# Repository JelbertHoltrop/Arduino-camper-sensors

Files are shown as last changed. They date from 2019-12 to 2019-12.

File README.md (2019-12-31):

# Arduino-camper-sensors
An arduino mega based board to monitor air quality, current usage, waste water tank level.
The board uses a BME680 sensor for temperature, pressure, humidity and VOC gas sensor.
For current it uses a INA280 current sensor
For the water level it uses tree elektrodes. Between two poles in the bottom of the tank a reference is taken to measure the condustiveness of the fluid, waste water changes conductivity. The other elektrode is a long bare wire (goldplated) and is used to measure the fluid level. 

Many of the Arduino MEGA 2560 pins are avaliable on screw terminals on the edge of the board. 7 digital lines have a ULN2003 driver output.
On the board is a 240x320 touch screen shield attached for the gui.
The schematic and PCB files are made in Eagle. The pcb is simple and single sided.

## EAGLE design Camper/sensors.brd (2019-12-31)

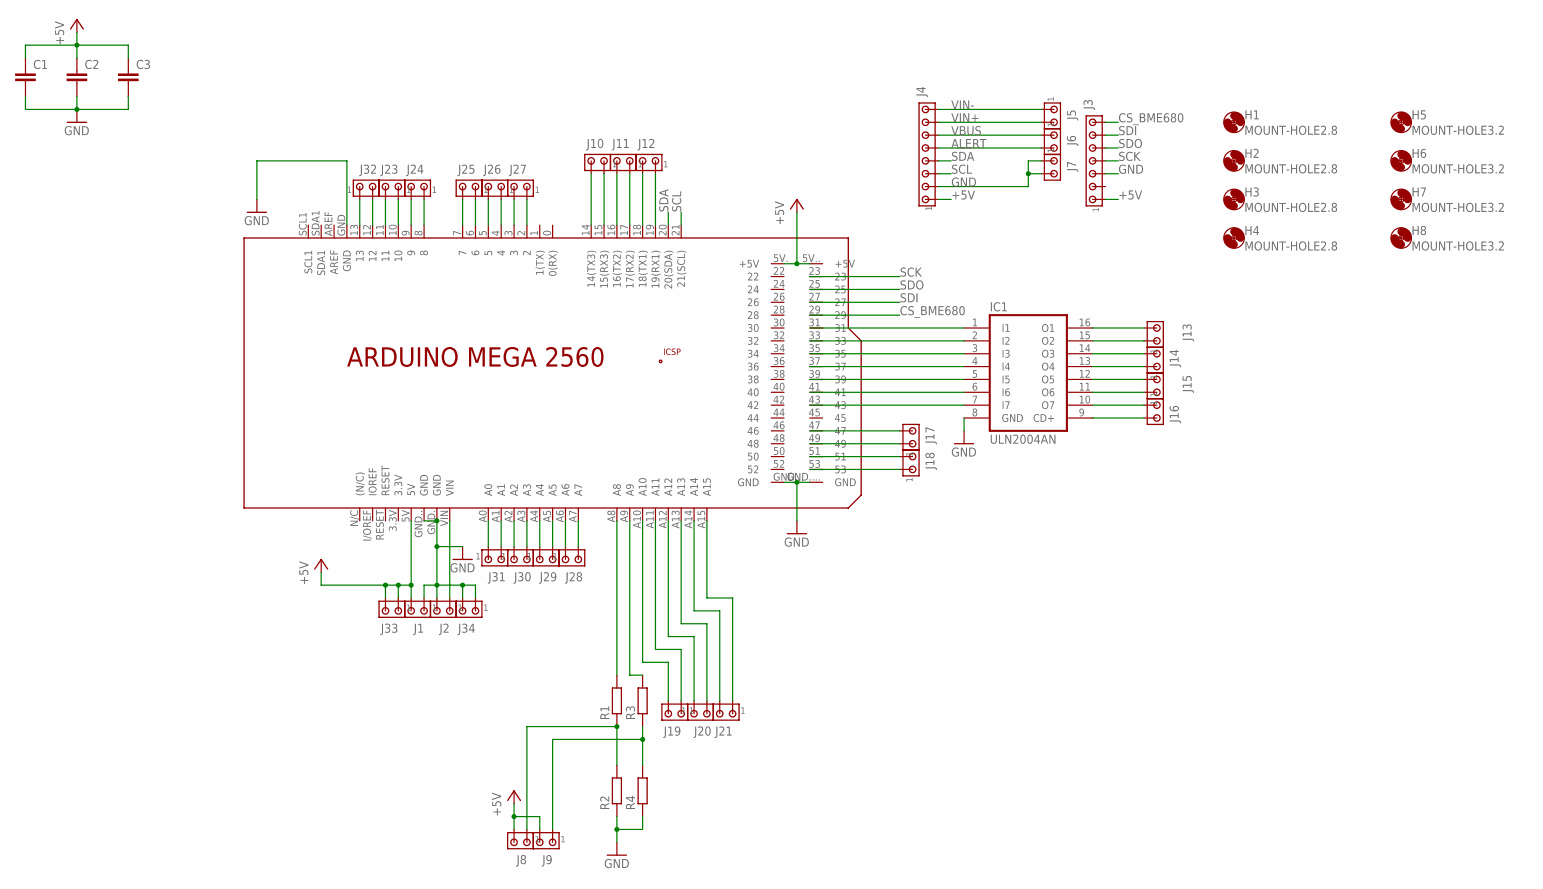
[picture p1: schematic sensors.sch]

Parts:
C1, C2, C3: C2,5-3; C2.5-3
H1, H2, H3, H4: MOUNT-HOLE2.8; 2,8
H5, H6, H7, H8: MOUNT-HOLE3.2; 3,2
IC1: ULN2004AN; DIL16
J1, J2, J5, J6, J7, J8, J9, J10, J11, J12, J13, J14, J15, J16, J17, J18, J19, J20, J21, J23, J24, J25, J26, J27, J28, J29, J30, J31, J32, J33, J34: SCREW-2
J3: MTA07-100; 10X07MTA
J4: MTA08-100; 10X08MTA
PCB1: ARDUINO_MEGA2560_NEW; ARDUINO_MEGA2560
R1, R2, R3, R4: R0207/10; 0207/10

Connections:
+5V: C1.1, C2.1, C3.1, J1.2, J3.1, J4.1, J8.2, J9.2, J33.1, J33.2, PCB1.5V, PCB1.5V. (+5V), PCB1.5V.. (+5V)
ALERT: J4.5, J6.2
CS_BME680: J3.7, PCB1.29
GND: C1.2, C2.2, C3.2, IC1.8 (GND), J1.1, J2.2, J3.3, J4.2, J7.1, J7.2, J34.1, J34.2, PCB1.GND, PCB1.GND. (GND), PCB1.GND.. (GND), PCB1.GND... (GND), PCB1.GND.... (GND), R2.1, R4.1
unnamed: J2.1, PCB1.VIN
unnamed: PCB1.A8, R1.2
unnamed: J8.1, R1.1, R2.2
unnamed: PCB1.A9, R3.2
unnamed: J9.1, R3.1, R4.2
unnamed: J19.2, PCB1.A10
unnamed: J19.1, PCB1.A11
unnamed: J20.1, PCB1.A12
unnamed: J20.2, PCB1.A13
unnamed: J21.2, PCB1.A14
unnamed: J21.1, PCB1.A15
unnamed: IC1.1 (I1), PCB1.31
unnamed: IC1.2 (I2), PCB1.33
unnamed: IC1.3 (I3), PCB1.35
unnamed: IC1.4 (I4), PCB1.37
unnamed: IC1.5 (I5), PCB1.39
unnamed: IC1.6 (I6), PCB1.41
unnamed: IC1.7 (I7), PCB1.43
unnamed: IC1.16 (O1), J13.2
unnamed: IC1.15 (O2), J13.1
unnamed: IC1.14 (O3), J14.2
unnamed: IC1.13 (O4), J14.1
unnamed: IC1.12 (O5), J15.2
unnamed: IC1.11 (O6), J15.1
unnamed: IC1.10 (O7), J16.1
unnamed: IC1.9 (CD+), J16.2
unnamed: J10.2, PCB1.14 (14(TX3))
unnamed: J10.1, PCB1.15 (15(RX3))
unnamed: J11.2, PCB1.16 (16(TX2))
unnamed: J11.1, PCB1.17 (17(RX2))
unnamed: J12.2, PCB1.18 (18(TX1))
unnamed: J12.1, PCB1.19 (19(RX1))
unnamed: J32.1, PCB1.13
unnamed: J32.2, PCB1.12
unnamed: J23.2, PCB1.11
unnamed: J23.1, PCB1.10
unnamed: J24.2, PCB1.9
unnamed: J24.1, PCB1.8
unnamed: J25.2, PCB1.7
unnamed: J25.1, PCB1.6
unnamed: J26.2, PCB1.5
unnamed: J26.1, PCB1.4
unnamed: J27.2, PCB1.3
unnamed: J27.1, PCB1.2
unnamed: J18.1, PCB1.53
unnamed: J18.2, PCB1.51
unnamed: J17.1, PCB1.49
unnamed: J17.2, PCB1.47
unnamed: J31.1, PCB1.A0
unnamed: J31.2, PCB1.A1
unnamed: J30.1, PCB1.A2
unnamed: J30.2, PCB1.A3
unnamed: J29.1, PCB1.A4
unnamed: J29.2, PCB1.A5
unnamed: J28.1, PCB1.A6
unnamed: J28.2, PCB1.A7
SCK: J3.4, PCB1.23
SCL: J4.3, PCB1.21 (21(SCL))
SDA: J4.4, PCB1.20 (20(SDA))
SDI: J3.6, PCB1.27
SDO: J3.5, PCB1.25
VBUS: J4.6, J6.1
VIN+: J4.7, J5.2
VIN-: J4.8, J5.1

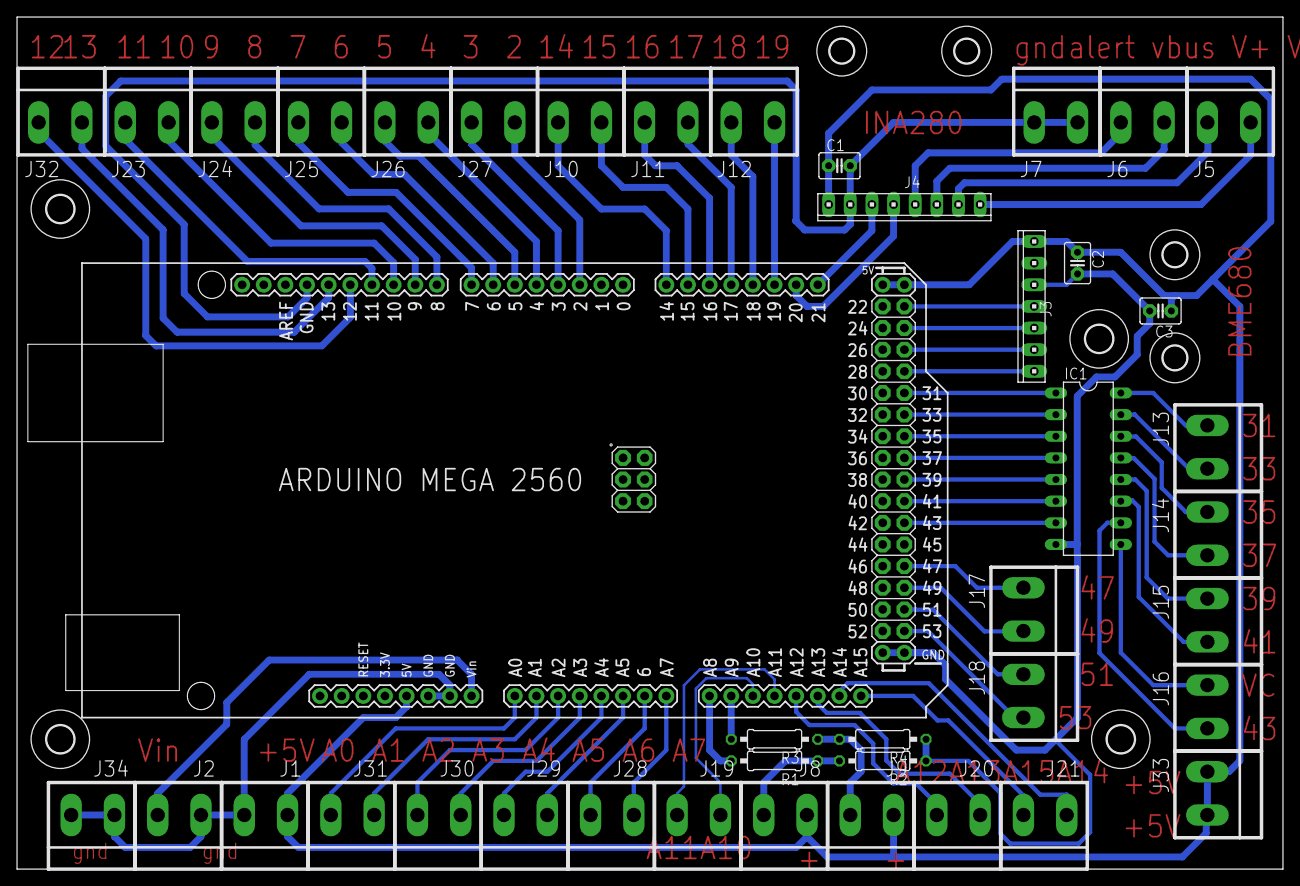
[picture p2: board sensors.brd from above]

Board: 2 copper layers, 148.6 x 100.0 mm, 50 parts (0 on the bottom side), 68 nets.

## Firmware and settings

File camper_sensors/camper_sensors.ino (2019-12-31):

/*
 * Arduino mega bordje gemaakt waar het display op past
 * Sensors:
 * BME680:
 * CS   29
 * SDI  27
 * SDO  25
 * SCK  23
 * 
 * Dit sensor heeft een afwijking ten gevolge van de temperatuur. dit zou een bug in de driver kunne zijn.
 * 
 * INA260
 * I2C
 * SDA  20
 * SCL  21
 * 
 * Water sensor: 2 elektroden in het water.
 * Onderste busje = common kleur zwart
 * tweede busje = ref kleur zwart
 * vergulde draad = meet kleur rood
 * ref: (Ref A8 & Common)twee contacten die een vaste afstand hebben van elkaar.
 * de weerstand in kraanwater is ca 5K 
 * op A8 zit 4K7 naar de aarde
 * als common 5V is staat hier dus 2.5V op 
 * meet: op de meet elektrode staat een weerstand van ca 217K als 
 * deze ondergedompeld is.
 * Op A9 zit een weerstand van 220K naar gnd.
 * Dus als de common op 5V zit staat hier met een volle tank ca 2.5V op.
 * Als het water zouter wordt zal de spanning op A8 hoger worden. Je zou dit als
 * refferentie voor een volle tank kunnen nemen. 
 * als A8 ~ 0v && A9 ~ 0V dan is het water nivo te laag, tank leeg
 * als A8 ~ 0V && A9 > 0V dan is referentie elektrode A8 stuk
 * 
 * 
 * 
 */

void setup() {
  // put your setup code here, to run once:

}

void loop() {
  // put your main code here, to run repeatedly:

}

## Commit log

2019-12-31 Update README.md
    added basic board info
2019-12-31 Add files via upload
    Eagle design files.
    [sensors.brd, sensors.sch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]
2019-12-31 Add files via upload
    first upload of arduino code.
    The sensor logs show the temprature drift of Rgas when the Adafruit libraries are used. The Adafruit libraries rely on BME680.c written by Bosch. The temprature drift is too big for any usefull usage of the BME680 in this project. To use the sensor the closed source library from Bosch is needed. Initially this would not compile but changes to platform.txt make this possible. The documentation on platform.txt by Bosch is faulty.
    The libraries and platform.txt will be added later, after I read their license agreement.
    [sensorlog.csv, sensorlog1.csv, sensorlog1a.ods]
